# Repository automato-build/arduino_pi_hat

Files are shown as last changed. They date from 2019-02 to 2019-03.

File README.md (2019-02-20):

# arduino_pi_serial HAT

#### TOP VIEW
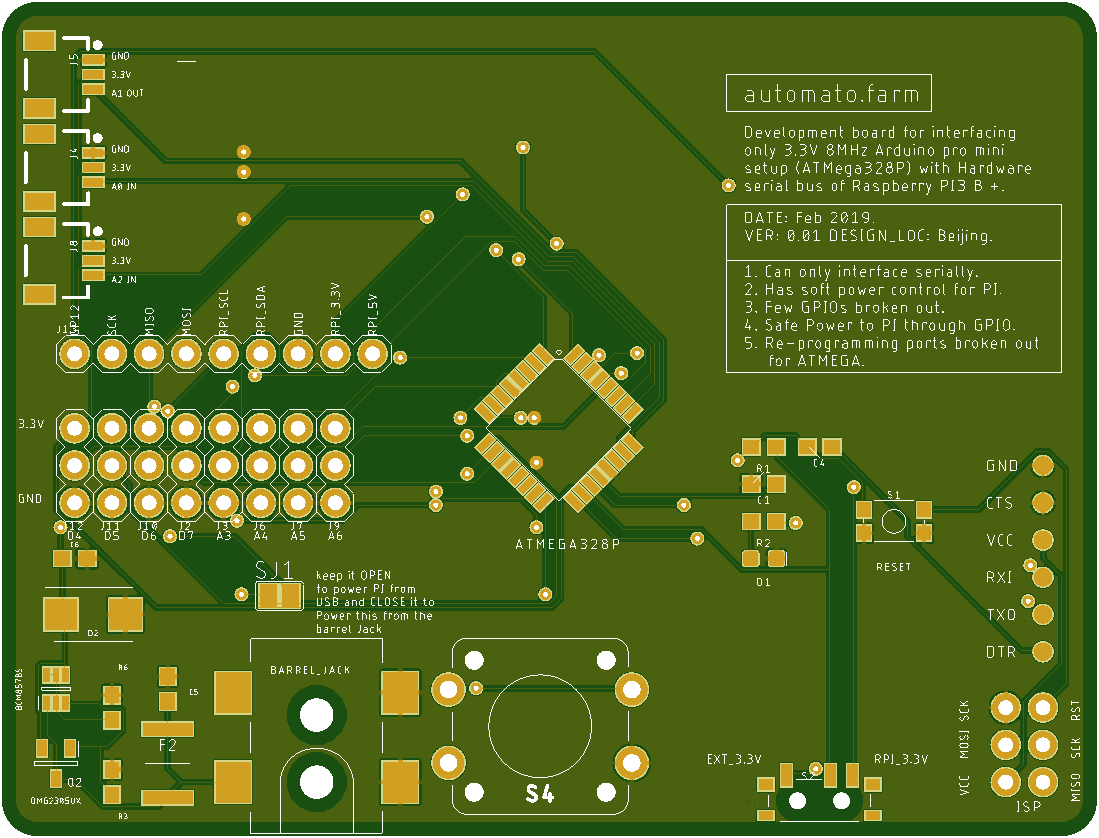
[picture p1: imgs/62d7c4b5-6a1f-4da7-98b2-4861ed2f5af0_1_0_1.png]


#### BOTTOM VIEW
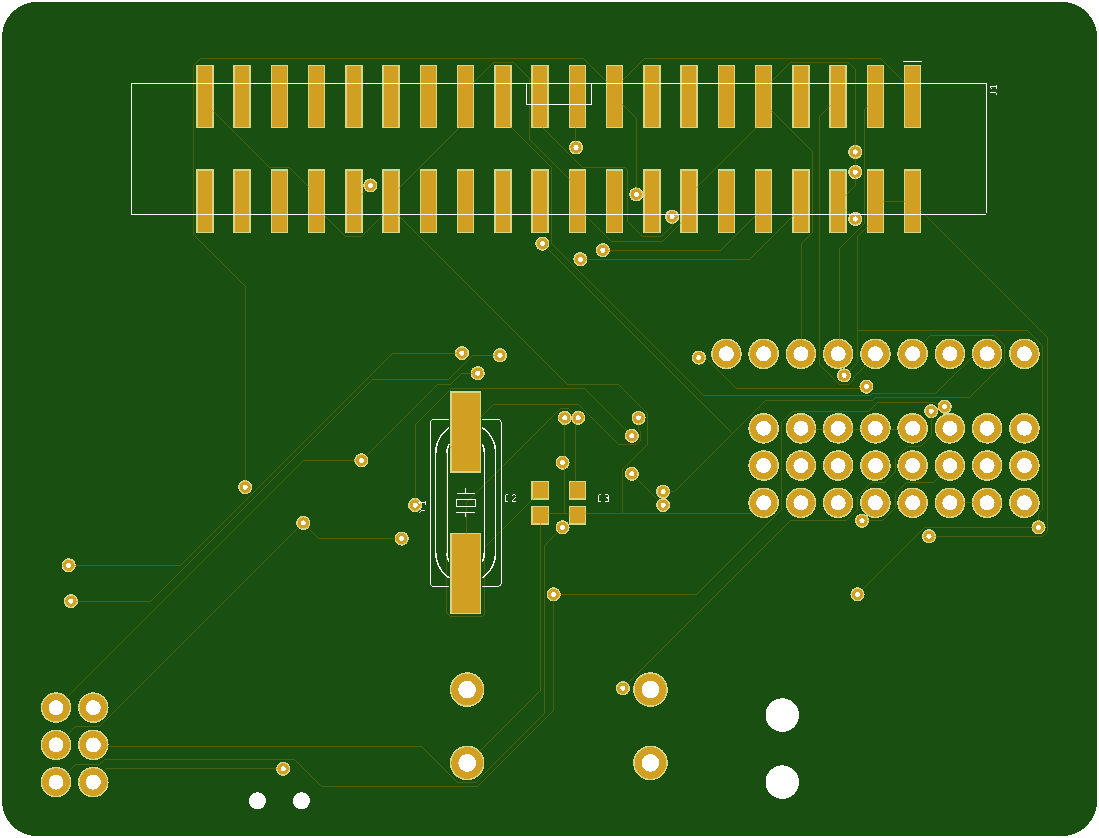
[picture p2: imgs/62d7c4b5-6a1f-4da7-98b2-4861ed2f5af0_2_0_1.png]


**Note:** _This is  part of a bigger project with automato.farm. This is just a small testing unit for some initial steps for next bigger ideas_

Assuming you are using [latest raspbian lite terminal only image](http://downloads.raspberrypi.org/raspbian/release_notes.txt) 
(we do not need GUI crap ATM).
Also assuming you have **updated**, **upgraded** and **set your locales** from the `raspi-config`. 

### CONFIGURE HARDWRAE SERIAL INTERFACE:
In `raspi-config`, under `interfaces` option **disbale console over serial** and then select **enable hardware serial**.

`sudo reboot`

Then run

`sudo ./setup_script.sh`

This sets fixes some setup

### A BIT ABOUT THE HARDWARE:
We are suing foot print of [Arduino Pro mini 3.3 V 8mHz](https://cdn.sparkfun.com/datasheets/Dev/Arduino/Boards/Arduino-Pro-Mini-v14.pdf) for the HAT in the schematic as PI's logic levels are all 3.3V. 
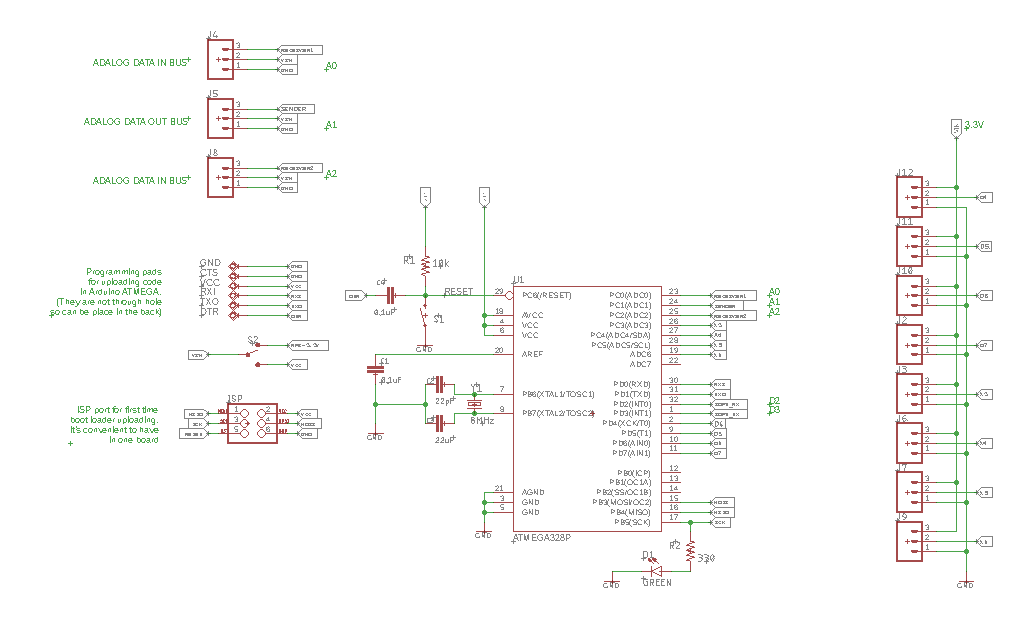
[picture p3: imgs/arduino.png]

We are also providing some external 5 Volt supply for which we have created some back current 
and voltage surge protection circuit following the guidelines of Raspvbberry pi HAT [design guides](https://github.com/raspberrypi/hats/blob/master/designguide.md)
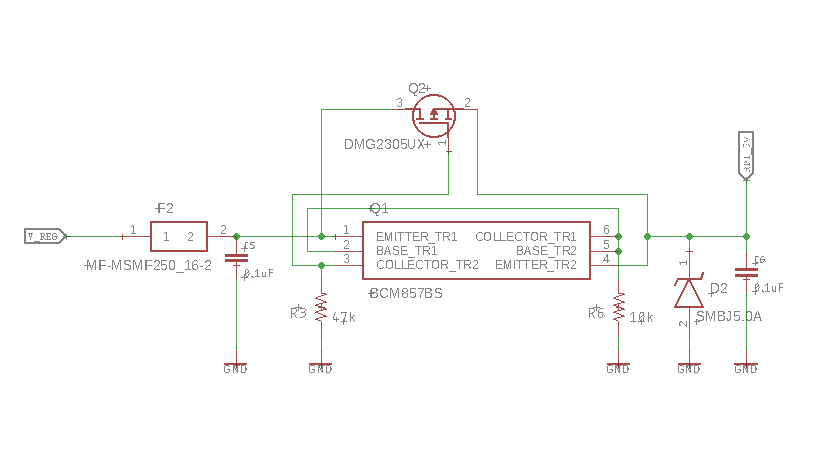
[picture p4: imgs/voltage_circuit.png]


Also we have provided some Breakout GPIO pins for both Arduino and PI. (**Note**: _Not all the pins are broken out.You mighht need to solder few wires._)

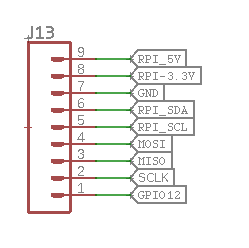
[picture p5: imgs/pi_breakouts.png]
PI's few breakouts

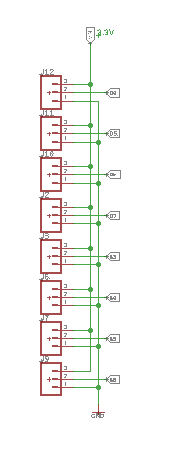
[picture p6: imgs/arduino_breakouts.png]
ATMega's few breakouts


We have also broken out ISP Ports for burning bootloader to ATMEga328. 
PLease [follow this guide](http://www.electronoobs.com/eng_arduino_tut6.php) here on how to do so. 
Only keep in mind few thing:
1. Use another Arduino Pro mini 3.3 V 8MHz as ISP programmer (folow the guide above on how to prepapre an Arduino for burning bootloader). Also use a 3.3 V logic enabled FTDI board for this master pro mini as pro minis do not have USB interface like pro micros. Don't forget to enable 3.3 V logic on it. Most boards have a jumper to switch between logic levels)
![]()
2. Also connect the ISP ports from this board (Will be marked on the baord) to the _MOSI_, _MISO_, _SCK_ and _CS_ pins of the programmer Arduino Pro mini. Rest follow the guide of burning bootloader.
3. Then you can use the same FTDI programmer  with the programming pads on the board to upload your code to the ATmega328.

In the design we have connected _PI's RX_ to Arduino's digital _pin 3_ and _PI's TX_ to Arduino's digital _pin 2_. We would be using **"SoftwareSerial"** lib on Arduino's side to confifure those pins as _software serial pins_ to establish serial communication with PI. This way we can keep the FTDI programmer attached to the programming pads on the baord to use Arduino's default Serial port for debugging the ATMega328.

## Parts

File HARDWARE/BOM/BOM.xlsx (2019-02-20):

Part | Value | Quantity | Device | Package | Description | Buying Link
C1 | 0.1uF | 100 | 0.1UF-0603-100V-10% | 603 | 0.1µF ceramic capacitors | https://detail.tmall.com/item.htm?spm=a1z0d.6639537.1997196601.1505.48db7484l4uUZ8&id=41231814882
C2 | 22pF | 100 | 0.1UF-0603-100V-10% | 603 | 22pF ceramic capacitors | https://detail.tmall.com/item.htm?spm=a1z0d.6639537.1997196601.1505.48db7484l4uUZ8&id=41231814882
D1 | GREEN | 100 | LED-GREEN 0603 | LED-0603 | Green SMD LED | https://detail.tmall.com/item.htm?spm=a1z0d.6639537.1997196601.1487.48db7484l4uUZ8&id=41231498462
D5 | SMBJ5.0A | 30 | Uni-Directional TVS Diode SMBJ5.0A-E3_52 | DIOM5436X244N | Vishay SMBJ5.0A-E3/52, Uni-Directional TVS Diode, 600W, 2-Pin DO-214AA | https://item.taobao.com/item.htm?spm=a1z0d.6639537.1997196601.15.352a7484rZSPDT&id=577425298915
F2 | MF-MSMF250_16-2 | 30 | MF-MSMF250_16-2 | FUSC4632X160N | BOURNS - MF-MSMF250/16-2 - FUSE, RESETTABLE PTC, 16V, 2.5A, 1812 | https://detail.tmall.com/item.htm?spm=a230r.1.14.40.230d4481tp6UpM&id=21976823684&ns=1&abbucket=6
J1 | 40-PIN-GPIO_SMT (2x20) | 20 | RASPBERRYPI-40-PIN-GPIO_SMT | 2X20_SHROUDED_SMT | Raspberry Pi GPIO Header | https://item.taobao.com/item.htm?spm=a1z0d.6639537.1997196601.24.352a7484rZSPDT&id=579021167159
Q1 | BCM857BS | 20 | BCM857BS | SOT65P210X110-6N | NEXPERIA - BCM857BS - TRANSISTOR, MATCHED, SOT-363 | https://item.taobao.com/item.htm?spm=a1z0d.6639537.1997196601.24.352a7484rZSPDT&id=579021167159
Q2 | DMG2305UX | 20 | DMG2305UXQ-7 | SOT96P240X102-3N | MOSFET MOSFET BVDSS | https://detail.tmall.com/item.htm?spm=a1z0d.6639537.1997196601.55.352a7484rZSPDT&id=536884160849
R1 | 10k | 50 | 10KOHM-0603-1/10W-1% | 603 | 10K resistor | https://detail.tmall.com/item.htm?spm=a1z0d.6639537.1997196601.65.352a7484rZSPDT&id=550090219082
R2 | 330 | 50 | 10KOHM-0603-1/10W-1% | 603 | 330 resistor | https://detail.tmall.com/item.htm?spm=a1z0d.6639537.1997196601.65.352a7484rZSPDT&id=550090219082
R3 | 47k | 50 | 10KOHM-0603-1/10W-1% | 603 | 47K resistor | https://detail.tmall.com/item.htm?spm=a1z0d.6639537.1997196601.65.352a7484rZSPDT&id=550090219082
S2 | SPDT switch | 20 | SWITCH-SPDT-SMD-RIGHT-ANGLE | SWITCH_SPST_SMD_A | Single Pole, Double Throw (SPDT) Switch | https://item.taobao.com/item.htm?spm=a1z0d.6639537.1997196601.4.352a7484BeYSjK&id=565055365474
U1 | ATMEGA328P | 10 | ATMEGA328P_TQFP | TQFP32-08 | Popular 328P in QFP ATMega microcontroller | https://item.taobao.com/item.htm?spm=a1z0d.6639537.1997196601.1320.48db7484l4uUZ8&id=17639962427
Y1 | 8MHz | 20 | CRYSTAL-8M HZS MD-HC49UP | HC49UP | 8MHz Crystal | https://detail.tmall.com/item.htm?spm=a1z0d.6639537.1997196601.1478.48db7484l4uUZ8&id=41227806820
jst
barrel jack SMT
big push button
male headers

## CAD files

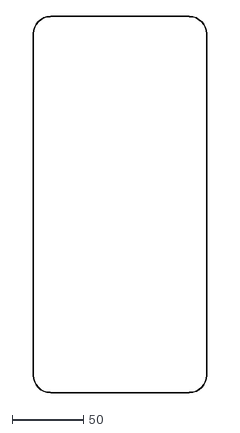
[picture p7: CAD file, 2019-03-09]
KICAD_PROJECTS/rpi_MECH_Zero_1p3.dxf
121.6 x 263.4

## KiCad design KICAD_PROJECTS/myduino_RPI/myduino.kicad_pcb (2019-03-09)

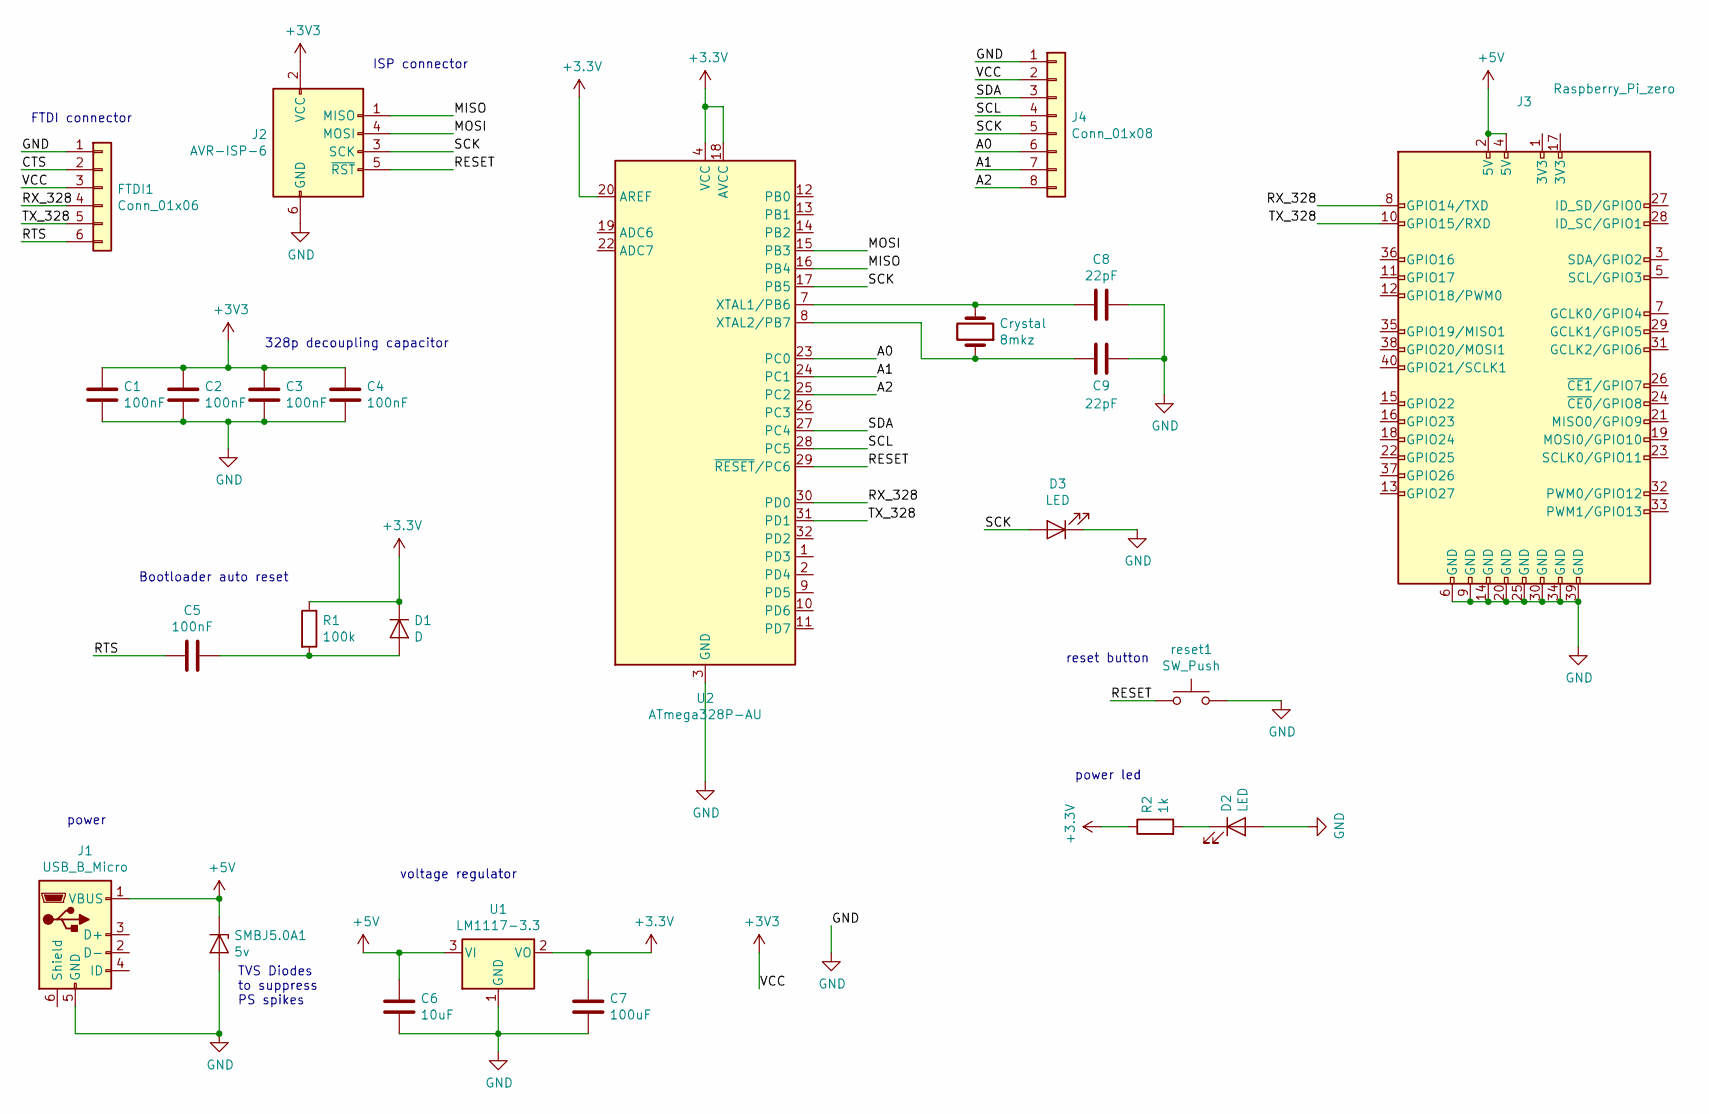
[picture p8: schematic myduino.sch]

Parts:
C1, C2, C3, C4, C5: 100nF; C_0805_2012Metric_Pad1.15x1.40mm_HandSolder
C6: 10uF; C_0805_2012Metric_Pad1.15x1.40mm_HandSolder
C7: 100uF; C_Elec_6.3x5.4
C8, C9: 22pF; C_0805_2012Metric_Pad1.15x1.40mm_HandSolder
Crystal: 8mkz; Crystal_SMD_HC49-SD
D1: D; D_0805_2012Metric
D2, D3: LED; LED_0805_2012Metric_Pad1.15x1.40mm_HandSolder
FTDI1: Conn_01x06; PinSocket_1x06_P2.54mm_Vertical
J1: USB_B_Micro; USB_Micro-B_Wuerth_629105150521_CircularHoles
J2: AVR-ISP-6; PinHeader_2x03_P2.54mm_Vertical
J3: Raspberry_Pi_zero; PinHeader_2x20_P2.54mm_Vertical_SMD
J4: Conn_01x08; PinSocket_1x08_P2.54mm_Vertical
R1: 100k; R_0805_2012Metric_Pad1.15x1.40mm_HandSolder
R2: 1k; R_0805_2012Metric_Pad1.15x1.40mm_HandSolder
SMBJ5.0A1: 5v; D_SMB
U1: LM1117-3.3; SOT-223-3_TabPin2
U2: ATmega328P-AU; TQFP-32_7x7mm_P0.8mm
reset1: SW_Push; SW_SPST_PTS645

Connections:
+5V: C6.1, J1.1 (VBUS), J3.2 (5V), J3.4 (5V), SMBJ5.0A1.1 (K), U1.3 (VI)
/A0: J4.6, U2.23 (PC0)
/A1: J4.7, U2.24 (PC1)
/A2: J4.8, U2.25 (PC2)
/CTS: FTDI1.2
/MISO: J2.1 (MISO), U2.16 (PB4)
/MOSI: J2.4 (MOSI), U2.15 (PB3)
/RESET: J2.5 (~RST), U2.29 (~RESET~/PC6), reset1.1
/RTS: C5.2, FTDI1.6; also elsewhere on the board
/RX_328: FTDI1.4, J3.8 (GPIO14/TXD), U2.30 (PD0)
/SCK: D3.2 (A), J2.3 (SCK), J4.5, U2.17 (PB5)
/SCL: J4.4, U2.28 (PC5)
/SDA: J4.3, U2.27 (PC4)
/TX_328: FTDI1.5, J3.10 (GPIO15/RXD), U2.31 (PD1)
GND: C1.2, C2.2, C3.2, C4.2, C6.2, C7.2, C8.1, C9.1, D2.2 (A), D3.1 (K), FTDI1.1, J1.5 (GND), J2.6 (GND), J3.6 (GND), J3.9 (GND), J3.14 (GND), J3.20 (GND), J3.25 (GND), J3.30 (GND), J3.34 (GND), J3.39 (GND), J4.1, SMBJ5.0A1.2 (A), U1.1 (GND), U2.3 (GND), U2.5 (GND), U2.21 (GND), reset1.2
unnamed: C5.1, D1.2 (A), R1.2
unnamed 17: C8.2, Crystal.2, U2.7 (XTAL1/PB6); also elsewhere on the board
unnamed 18: C9.2, Crystal.1, U2.8 (XTAL2/PB7); also elsewhere on the board
unnamed: D2.1 (K), R2.2

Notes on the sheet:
328p decoupling capacitor
reset button
Bootloader auto reset
ISP connector
power
voltage regulator
FTDI connector
power led
TVS Diodes to suppress PS spikes

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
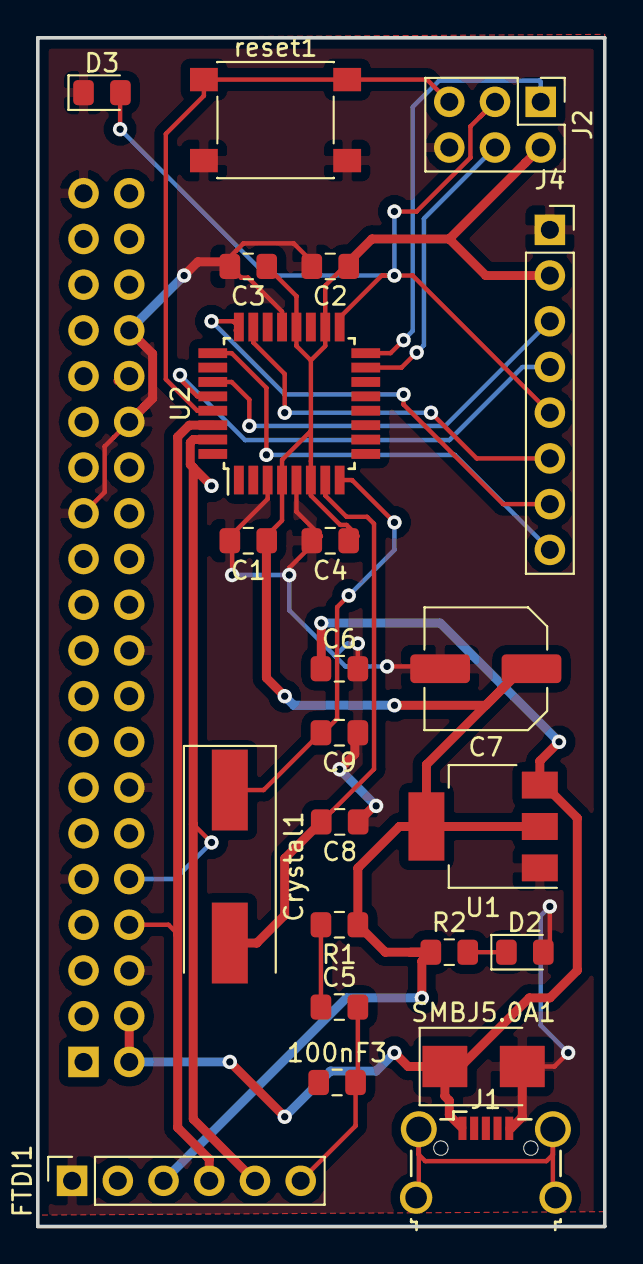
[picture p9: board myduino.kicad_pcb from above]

Board: 2 copper layers, 31.5 x 66.0 mm, 24 parts (1 on the bottom side), 19 nets.

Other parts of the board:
100nF3: C; C_0805_2012Metric_Pad1.15x1.40mm_HandSolder
Crystal1: 8mkz; Crystal_SMD_HC49-SD

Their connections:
/RTS: 100nF3.2; also elsewhere on the board
unnamed 17: Crystal1.2; also elsewhere on the board
unnamed 18: Crystal1.1; also elsewhere on the board

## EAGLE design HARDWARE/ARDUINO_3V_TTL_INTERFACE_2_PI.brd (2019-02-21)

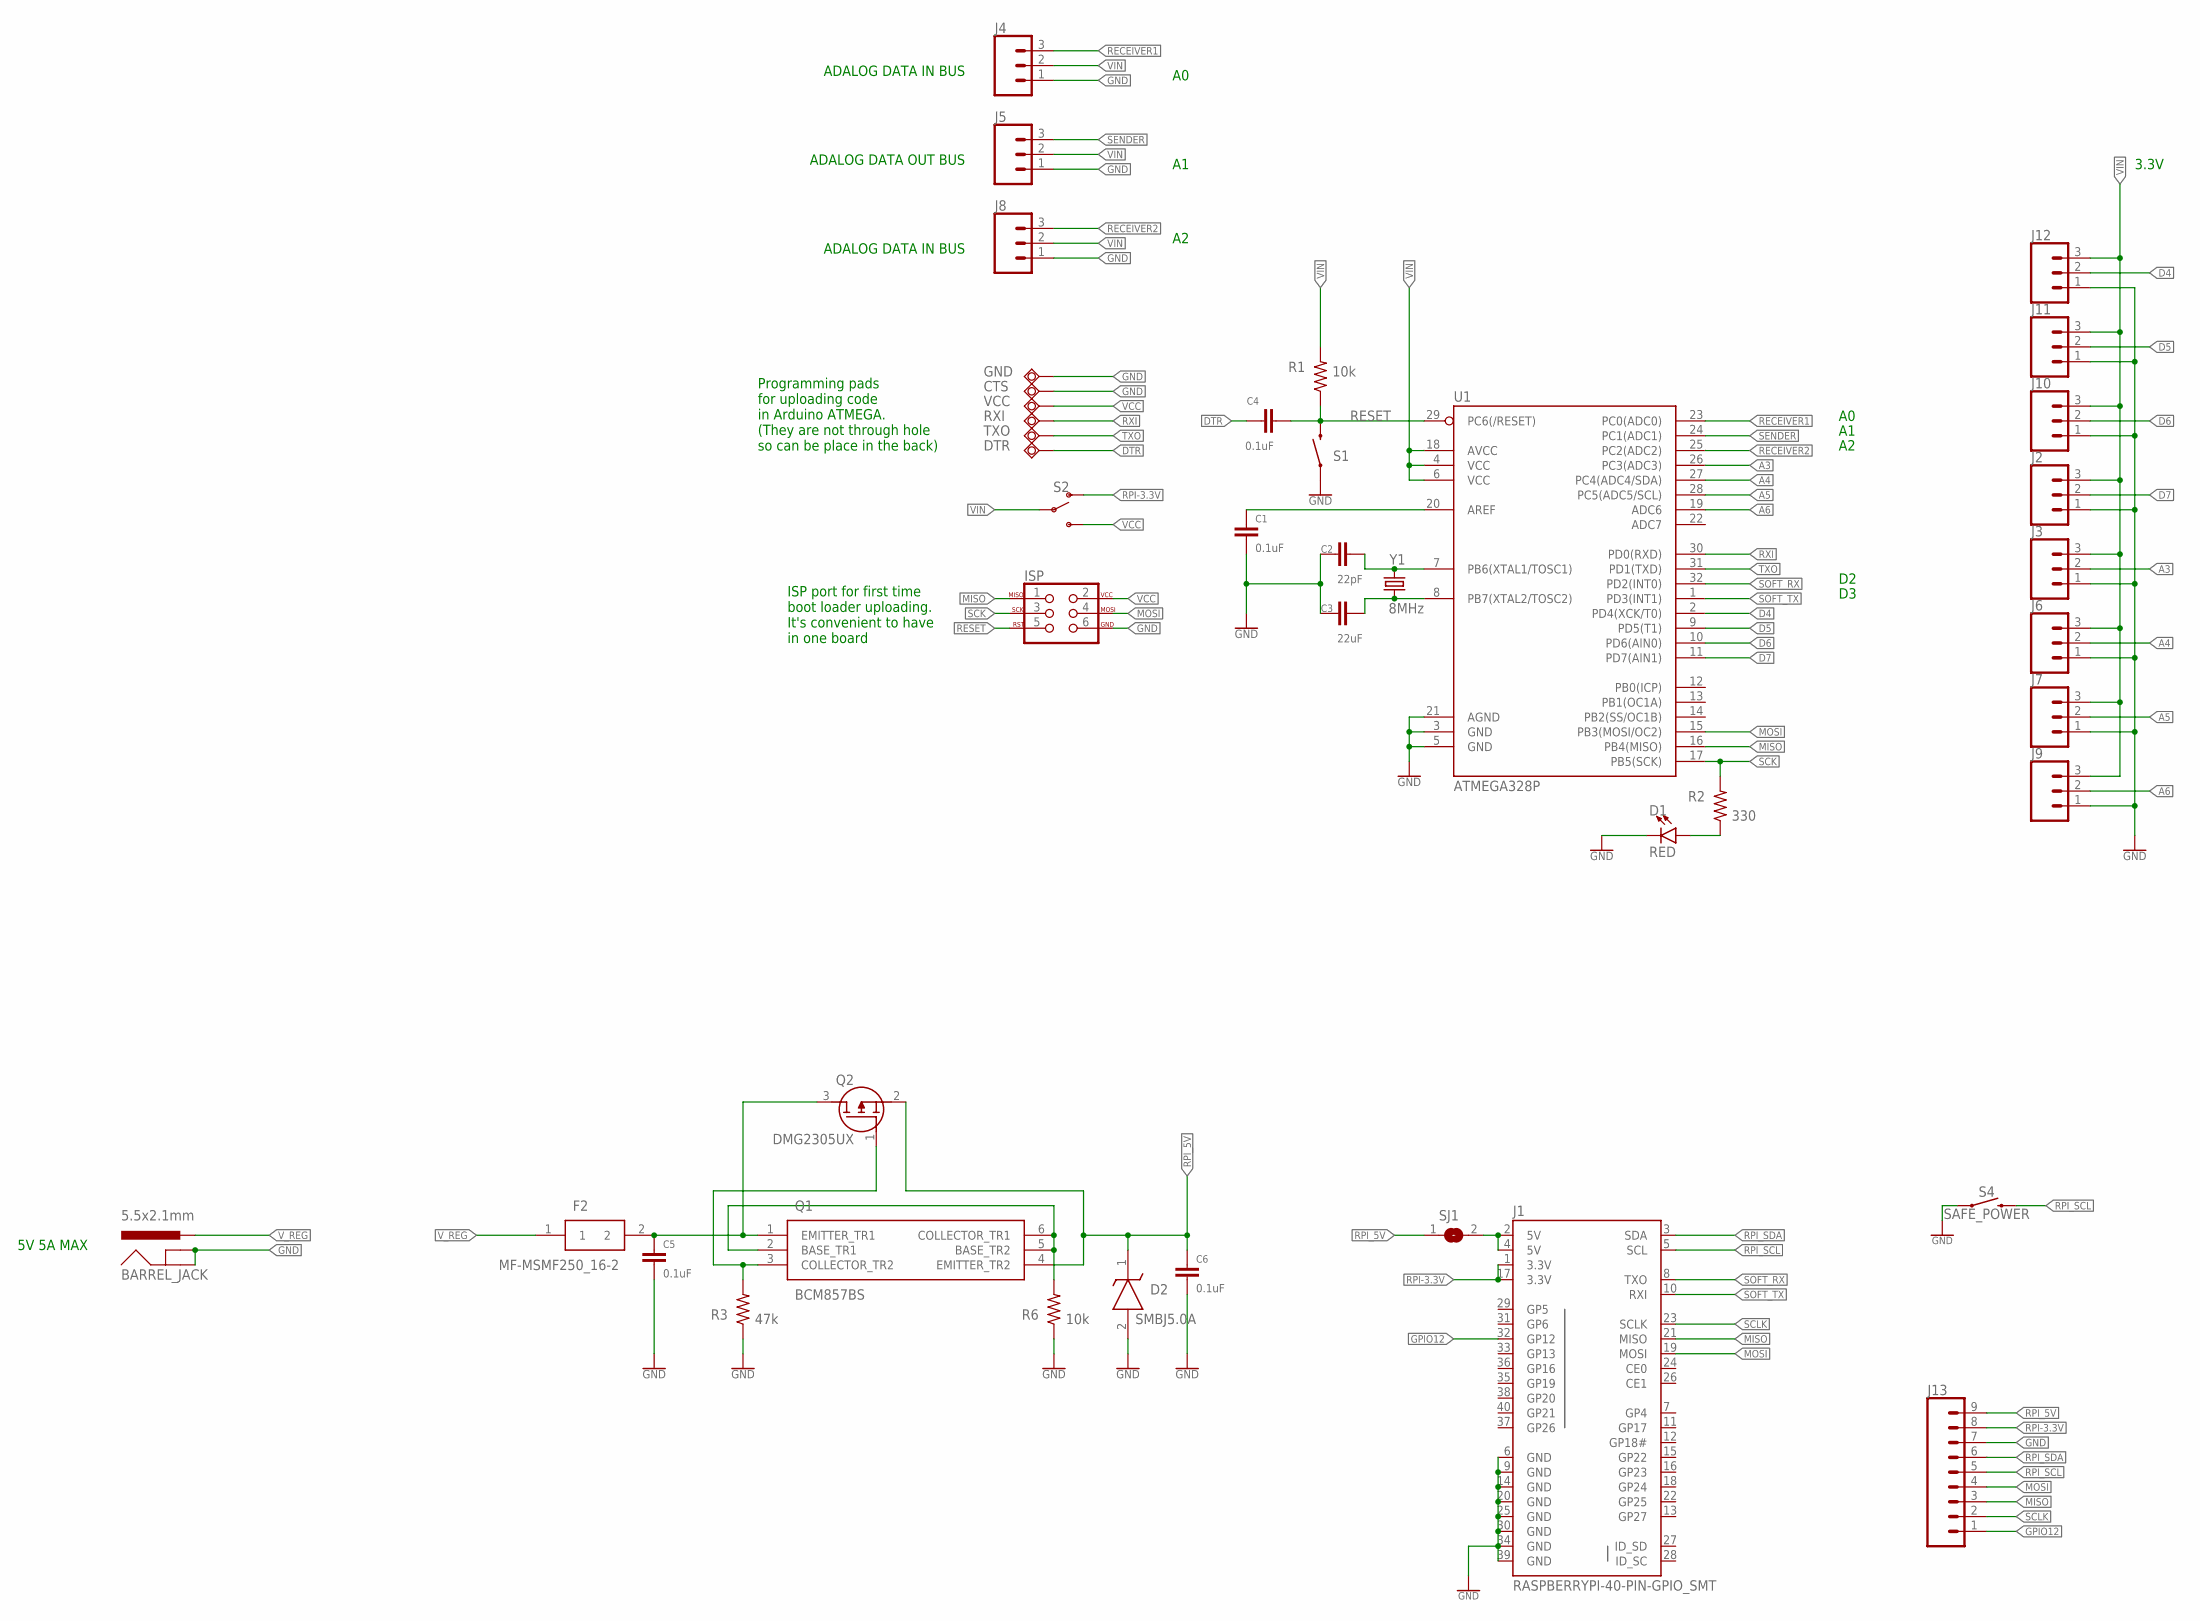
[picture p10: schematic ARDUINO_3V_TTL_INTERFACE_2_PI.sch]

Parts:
BARREL_JACK: 5.5x2.1mm; POWER_JACK_SMD
C1, C4, C5, C6: 0.1uF; 0603
C2: 22pF; 0603
C3: 22uF; 0603
CTS: TPSQB1,27; B1,27
D1: RED; LED-0603
D2: SMBJ5.0A; DIOM5436X244N
DTR: TPSQB1,27; B1,27
F2: MF-MSMF250_16-2; FUSC4632X160N
GND: TPSQB1,27; B1,27
ISP: AVR_SPI_PROG_3X2NS; 2X3-NS
J1: RASPBERRYPI-40-PIN-GPIO_SMT; 2X20_SHROUDED_SMT
J2, J3, J6, J7, J9, J10, J11, J12: CONN_03; 1X03
J4, J5, J8: CONN_03SMD; 1X03-1MM-RA
J13: CONN_09; 1X09
Q1: BCM857BS; SOT65P210X110-6N
Q2: DMG2305UX; SOT96P240X102-3N
R1, R6: 10k; 0603
R2: 330; 0603
R3: 47k; 0603
RXI: TPSQB1,27; B1,27
S1: RESET; TACTILE_SWITCH_SMD_4.6X2.8MM
S2: SWITCH-SPDT-SMD-RIGHT-ANGLE; SWITCH_SPST_SMD_A
S4: SAFE_POWER; TACTILE_SWITCH_PTH_12MM
SJ1: SJ
TXO: TPSQB1,27; B1,27
U1: ATMEGA328P; TQFP32-08
VCC: TPSQB1,27; B1,27
Y1: 8MHz; HC49UP

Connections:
A3: J3.2, U1.26 (PC3(ADC3))
A4: J6.2, U1.27 (PC4(ADC4/SDA))
A5: J7.2, U1.28 (PC5(ADC5/SCL))
A6: J9.2, U1.19 (ADC6)
D4: J12.2, U1.2 (PD4(XCK/T0))
D5: J11.2, U1.9 (PD5(T1))
D6: J10.2, U1.10 (PD6(AIN0))
D7: J2.2, U1.11 (PD7(AIN1))
DTR: C4.1, DTR.TP
GND: BARREL_JACK.GND (GNDBREAK), BARREL_JACK.P$4 (GND), C1.2, C2.1, C3.1, C5.2, C6.2, CTS.TP, D1.C, D2.2 (A), GND.TP, ISP.6, J1.6 (GND), J1.9 (GND), J1.14 (GND), J1.20 (GND), J1.25 (GND), J1.30 (GND), J1.34 (GND), J1.39 (GND), J2.1, J3.1, J4.1, J5.1, J6.1, J7.1, J8.1, J9.1, J10.1, J11.1, J12.1, J13.7, R3.1, R6.1, S1.1, S1.2 (1), S4.1, U1.3 (GND), U1.5 (GND), U1.21 (AGND)
GPIO12: J1.32 (GP12), J13.1
MISO: ISP.1, J1.21 (MISO), J13.3, U1.16 (PB4(MISO))
MOSI: ISP.4, J1.19 (MOSI), J13.4, U1.15 (PB3(MOSI/OC2))
unnamed: C1.1, U1.20 (AREF)
unnamed: J1.2 (5V), J1.4 (5V), SJ1.2
unnamed: D1.A, R2.1
unnamed: Q1.3 (COLLECTOR_TR2), Q2.1 (G), R3.2
unnamed: Q1.2 (BASE_TR1), Q1.5 (BASE_TR2), Q1.6 (COLLECTOR_TR1), R6.2
unnamed: C2.2, U1.7 (PB6(XTAL1/TOSC1)), Y1.2
unnamed: C3.2, U1.8 (PB7(XTAL2/TOSC2)), Y1.1
RECEIVER1: J4.3, U1.23 (PC0(ADC0))
RECEIVER2: J8.3, U1.25 (PC2(ADC2))
RESET: C4.2, ISP.5, R1.1, S1.3 (2), S1.4 (2), U1.29 (PC6(/RESET))
RPI-3.3V: J1.1 (3.3V), J1.17 (3.3V), J13.8, S2.1 (O)
RPI_5V: C6.1, D2.1 (K), J13.9, Q1.4 (EMITTER_TR2), Q2.2 (S), SJ1.1
RPI_SCL: J1.5 (SCL), J13.5, S4.3 (2)
RPI_SDA: J1.3 (SDA), J13.6
RXI: RXI.TP, U1.30 (PD0(RXD))
SCK: ISP.3, R2.2, U1.17 (PB5(SCK))
SCLK: J1.23 (SCLK), J13.2
SENDER: J5.3, U1.24 (PC1(ADC1))
SOFT_RX: J1.8 (TXO), U1.32 (PD2(INT0))
SOFT_TX: J1.10 (RXI), U1.1 (PD3(INT1))
TXO: TXO.TP, U1.31 (PD1(TXD))
VCC: ISP.2, S2.3 (S), VCC.TP
VIN: J2.3, J3.3, J4.2, J5.2, J6.3, J7.3, J8.2, J9.3, J10.3, J11.3, J12.3, R1.2, S2.2, U1.4 (VCC), U1.6 (VCC), U1.18 (AVCC)
V_REG: BARREL_JACK.VIN0 (PWR), C5.1, F2.1, F2.2, Q1.1 (EMITTER_TR1), Q2.3 (D)

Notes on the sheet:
ADALOG DATA IN BUS
ADALOG DATA OUT BUS
Programming pads for uploading code in Arduino ATMEGA. (They are not through hole so can be place in the back)
ISP port for first time boot loader uploading. It's convenient to have in one board
5V 5A MAX
3.3V

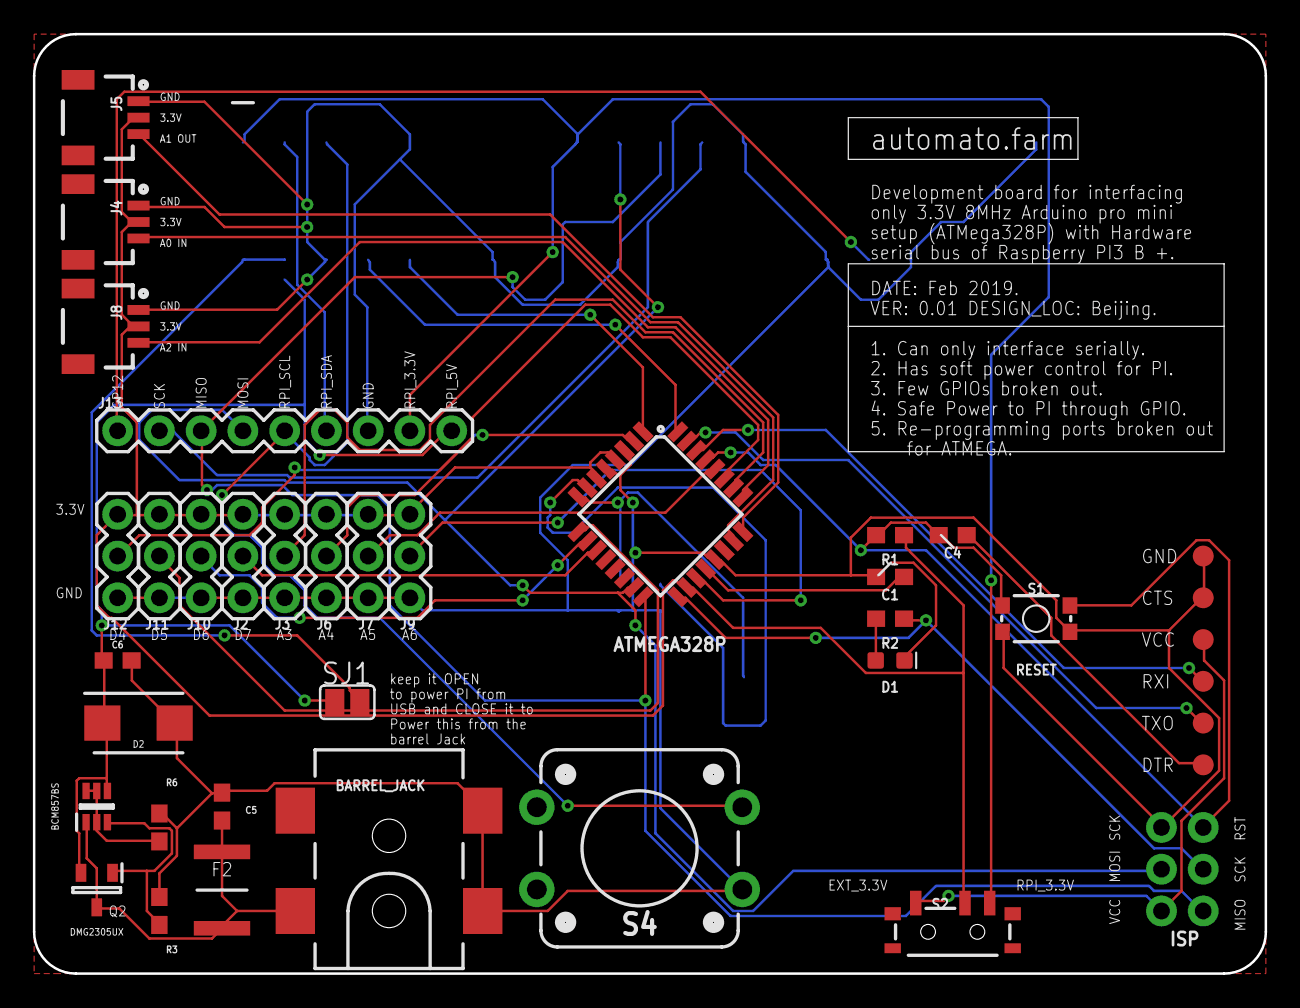
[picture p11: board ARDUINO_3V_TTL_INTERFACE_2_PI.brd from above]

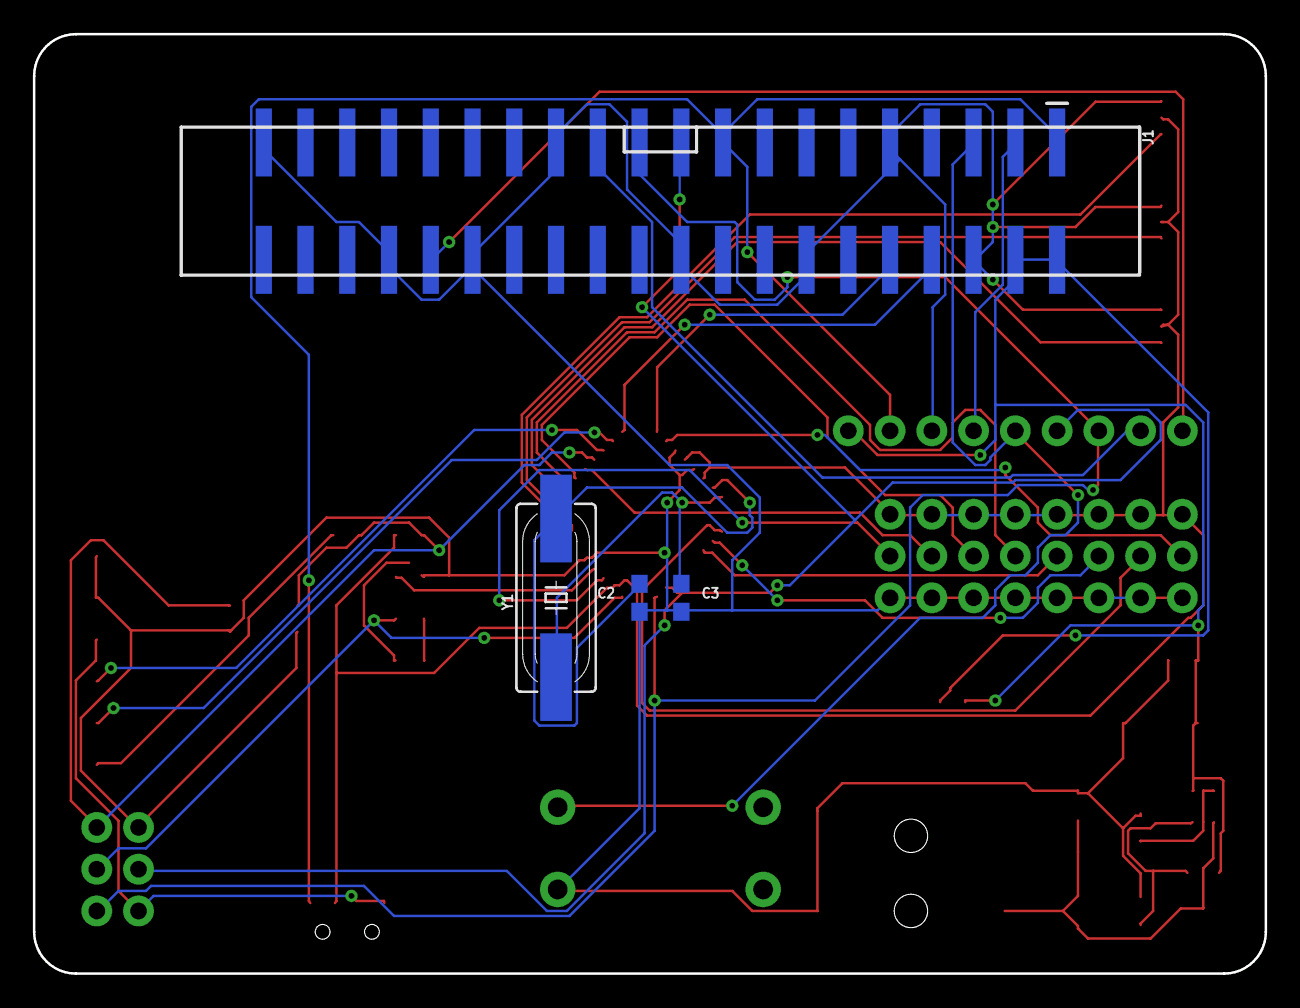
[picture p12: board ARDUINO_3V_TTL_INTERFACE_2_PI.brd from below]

Board: 2 copper layers, 74.9 x 57.1 mm, 42 parts (4 on the bottom side), 37 nets.

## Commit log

2019-02-20 added sample raspi side python serail scripts
2019-02-20 PCB's images
2019-02-21 checkiong migration to new profile
    [ARDUINO_3V_TTL_INTERFACE_2_PI.sch]
2019-02-21 added a jumper to separate ext voltage for testing it the volt reg citcuit doesn't work
    [ARDUINO_3V_TTL_INTERFACE_2_PI.brd, ARDUINO_3V_TTL_INTERFACE_2_PI.sch]
2019-02-21 up-dated read me with new preview image including the new voltage separation jumper
2019-03-09 add lorenzo's pihat design
    [_saved_myduino.sch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]

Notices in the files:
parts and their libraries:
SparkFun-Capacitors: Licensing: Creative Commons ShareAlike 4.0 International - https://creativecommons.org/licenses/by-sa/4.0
